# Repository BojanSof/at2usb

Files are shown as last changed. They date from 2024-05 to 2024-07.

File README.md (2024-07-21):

# AT (PS/2) keyboard to USB converter

PIC16F1459 solution for converting old AT (PS/2) keyboard to USB.

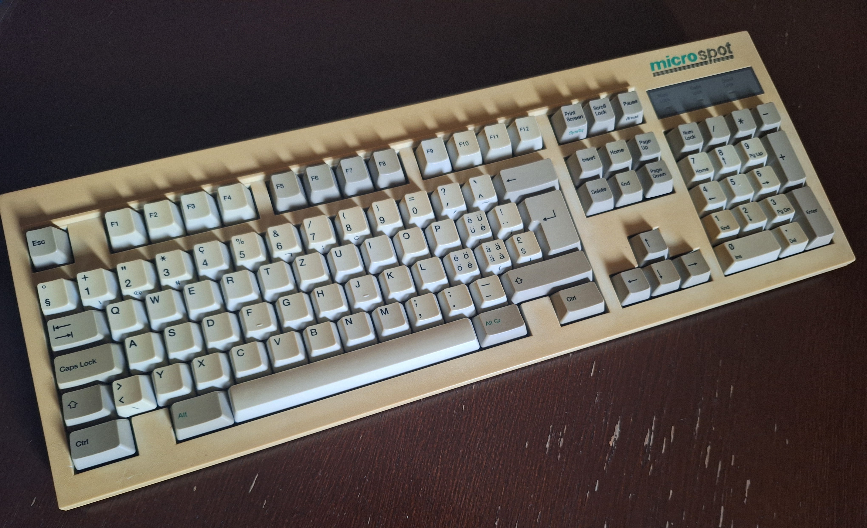
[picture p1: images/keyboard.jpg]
AT keyboard transformed to USB


## Hardware

Schematic and one layer PCB can be found under `hardware` directory.
The hardware design is created using KiCad 7.0.
The circuit is very simple and it can be created easily on prototyping board.

AT2USB schematic

## Firmware

The firmware is developed with MPLAB X IDE, found under `at2usbClassic.X` directory.
USB stack implementation and main HID app code is based on USB HID keyboard project from [Microchip Libraries for Applications (MLA)](https://www.microchip.com/en-us/tools-resources/develop/libraries/microchip-libraries-for-applications).

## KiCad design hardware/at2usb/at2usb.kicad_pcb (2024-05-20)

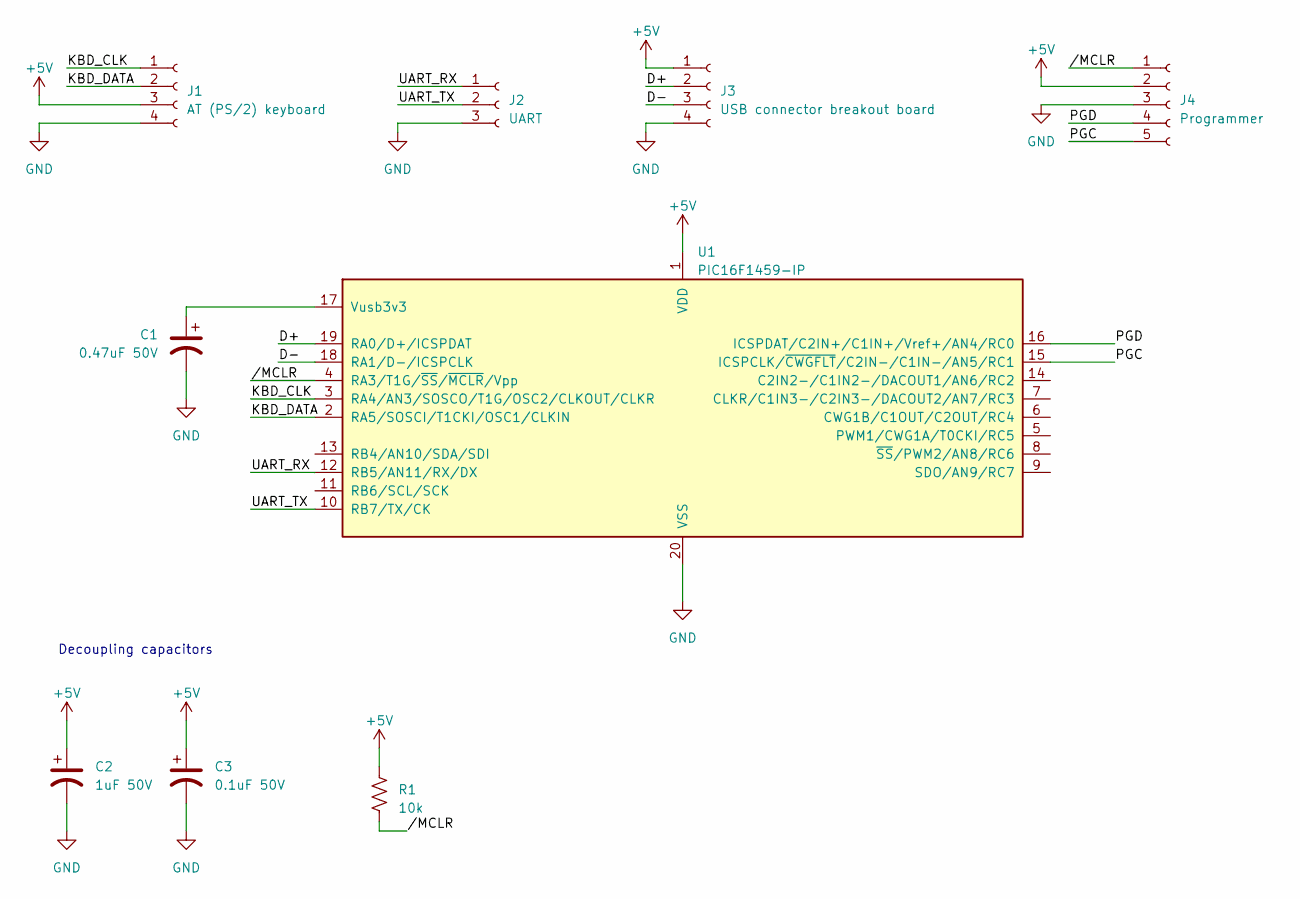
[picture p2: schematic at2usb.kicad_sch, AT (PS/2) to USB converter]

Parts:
C1: 0.47uF 50V; CP_Radial_D5.0mm_P2.00mm
C2: 1uF 50V; CP_Radial_D5.0mm_P2.00mm
C3: 0.1uF 50V; CP_Radial_D5.0mm_P2.00mm
J1: AT (PS/2) keyboard; PinHeader_1x04_P2.54mm_Vertical
J2: UART; PinHeader_1x03_P2.54mm_Vertical
J3: USB connector breakout board; PinHeader_1x04_P2.54mm_Vertical
J4: Programmer; PinHeader_1x05_P2.54mm_Vertical
R1: 10k; R_Axial_DIN0207_L6.3mm_D2.5mm_P2.54mm_Vertical
U1: PIC16F1459-IP; DIP-20_W7.62mm_Socket

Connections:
+5V: C2.1, C3.1, J1.3, J3.1, J4.2, R1.1, U1.1 (VDD)
/D+: J3.2, U1.19 (RA0/D+/ICSPDAT)
/D-: J3.3, U1.18 (RA1/D-/ICSPCLK)
/KBD_CLK: J1.1, U1.3 (RA4/AN3/SOSCO/T1G/OSC2/CLKOUT/CLKR)
/KBD_DATA: J1.2, U1.2 (RA5/SOSCI/T1CKI/OSC1/CLKIN)
/PGC: J4.5, U1.15 (ICSPCLK/~CWGFLT/C2IN-/C1IN-/AN5/RC1)
/PGD: J4.4, U1.16 (ICSPDAT/C2IN+/C1IN+/Vref+/AN4/RC0)
/UART_RX: J2.1, U1.12 (RB5/AN11/RX/DX)
/UART_TX: J2.2, U1.10 (RB7/TX/CK)
//MCLR: J4.1, R1.2, U1.4 (RA3/T1G/~SS/~MCLR/Vpp)
GND: C1.2, C2.2, C3.2, J1.4, J2.3, J3.4, J4.3, U1.20 (VSS)
unnamed: C1.1, U1.17 (Vusb3v3)

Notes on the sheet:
Decoupling capacitors

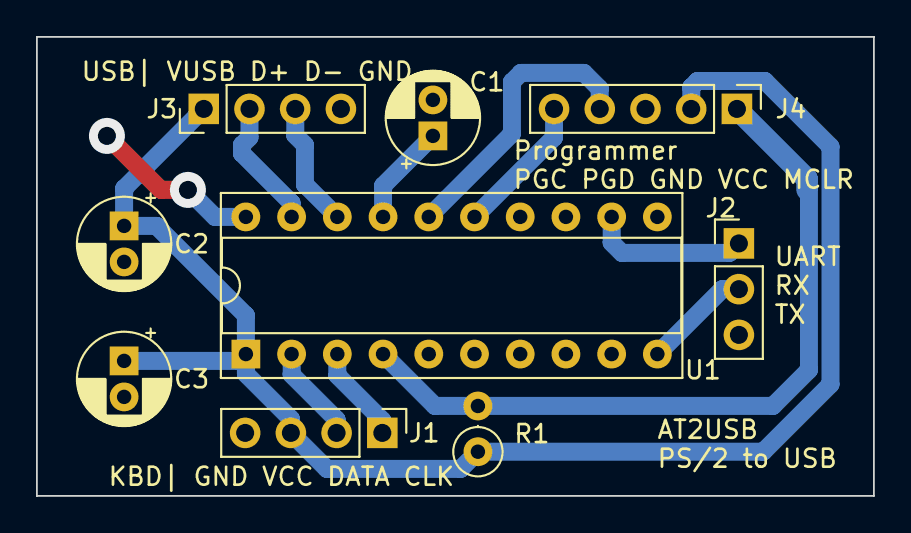
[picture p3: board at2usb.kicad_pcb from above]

Board: 2 copper layers, 46.5 x 25.5 mm, 9 parts (0 on the bottom side), 12 nets.

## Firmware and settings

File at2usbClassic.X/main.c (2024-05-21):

#include "mcc_generated_files/mcc.h"

#include "app_device_keyboard.h"
#include "systime.h"
#include "log.h"

/*
    Main application
 */

int main(void) {
    SYSTEM_Initialize();
    SysTime_Init();
    PS2Keyboard_Init();
    
    __delay_ms(1000);

    // If using interrupts in PIC18 High/Low Priority Mode you need to enable the Global High and Low Interrupts 
    // If using interrupts in PIC Mid-Range Compatibility Mode you need to enable the Global and Peripheral Interrupts 
    // Use the following macros to: 

    // Enable the Global Interrupts 
    INTERRUPT_GlobalInterruptEnable();

    // Enable the Peripheral Interrupts 
    INTERRUPT_PeripheralInterruptEnable();

    // Disable the Peripheral Interrupts 
    //INTERRUPT_PeripheralInterruptDisable();
    
    PS2ScanCode scanCode = {0};
    bool scanCodeValid = false;
    PS2ScanCode *hndlScanCode = NULL;
    char scanCodeStr[6] = {' ', ' ', ' ', ' ', '\r', '\n'};
    
    while (1) {
        scanCodeValid = PS2Keyboard_GetScanCode(&scanCode);
        if(scanCodeValid) {
            hndlScanCode = &scanCode;
        } else {
            hndlScanCode = NULL;
        }
        if(hndlScanCode != NULL) {
            scanCodeStr[0] = hndlScanCode->isExtend ? 'e' : ' ';
            scanCodeStr[1] = hndlScanCode->isBreak ? 'b' : ' ';
            Log_UtilityConvertByteToHex(hndlScanCode->value, &scanCodeStr[2], 2);
            Log_Message((const uint8_t*)scanCodeStr, sizeof(scanCodeStr));
        }
        APP_KeyboardTasks(hndlScanCode);
    }
}

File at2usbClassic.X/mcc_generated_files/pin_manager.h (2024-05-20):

/**
  @Generated Pin Manager Header File

  @Company:
    Microchip Technology Inc.

  @File Name:
    pin_manager.h

  @Summary:
    This is the Pin Manager file generated using PIC10 / PIC12 / PIC16 / PIC18 MCUs

  @Description
    This header file provides APIs for driver for .
    Generation Information :
        Product Revision  :  PIC10 / PIC12 / PIC16 / PIC18 MCUs - 1.81.8
        Device            :  PIC16F1459
        Driver Version    :  2.11
    The generated drivers are tested against the following:
        Compiler          :  XC8 2.36 and above
        MPLAB 	          :  MPLAB X 6.00	
*/

/*
    (c) 2018 Microchip Technology Inc. and its subsidiaries. 
    
    Subject to your compliance with these terms, you may use Microchip software and any 
    derivatives exclusively with Microchip products. It is your responsibility to comply with third party 
    license terms applicable to your use of third party software (including open source software) that 
    may accompany Microchip software.
    
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
    IN NO EVENT WILL MICROCHIP BE LIABLE FOR ANY INDIRECT, SPECIAL, PUNITIVE, 
    INCIDENTAL OR CONSEQUENTIAL LOSS, DAMAGE, COST OR EXPENSE OF ANY KIND 
    WHATSOEVER RELATED TO THE SOFTWARE, HOWEVER CAUSED, EVEN IF MICROCHIP 
    HAS BEEN ADVISED OF THE POSSIBILITY OR THE DAMAGES ARE FORESEEABLE. TO 
    THE FULLEST EXTENT ALLOWED BY LAW, MICROCHIP'S TOTAL LIABILITY ON ALL 
    CLAIMS IN ANY WAY RELATED TO THIS SOFTWARE WILL NOT EXCEED THE AMOUNT 
    OF FEES, IF ANY, THAT YOU HAVE PAID DIRECTLY TO MICROCHIP FOR THIS 
    SOFTWARE.
*/

#ifndef PIN_MANAGER_H
#define PIN_MANAGER_H

/**
  Section: Included Files
*/

#include <xc.h>

#define INPUT   1
#define OUTPUT  0

#define HIGH    1
#define LOW     0

#define ANALOG      1
#define DIGITAL     0

#define PULL_UP_ENABLED      1
#define PULL_UP_DISABLED     0

// get/set KBD_CLK aliases
#define KBD_CLK_TRIS                 TRISAbits.TRISA4
#define KBD_CLK_LAT                  LATAbits.LATA4
#define KBD_CLK_PORT                 PORTAbits.RA4
#define KBD_CLK_WPU                  WPUAbits.WPUA4
#define KBD_CLK_ANS                  ANSELAbits.ANSA4
#define KBD_CLK_SetHigh()            do { LATAbits.LATA4 = 1; } while(0)
#define KBD_CLK_SetLow()             do { LATAbits.LATA4 = 0; } while(0)
#define KBD_CLK_Toggle()             do { LATAbits.LATA4 = ~LATAbits.LATA4; } while(0)
#define KBD_CLK_GetValue()           PORTAbits.RA4
#define KBD_CLK_SetDigitalInput()    do { TRISAbits.TRISA4 = 1; } while(0)
#define KBD_CLK_SetDigitalOutput()   do { TRISAbits.TRISA4 = 0; } while(0)
#define KBD_CLK_SetPullup()          do { WPUAbits.WPUA4 = 1; } while(0)
#define KBD_CLK_ResetPullup()        do { WPUAbits.WPUA4 = 0; } while(0)
#define KBD_CLK_SetAnalogMode()      do { ANSELAbits.ANSA4 = 1; } while(0)
#define KBD_CLK_SetDigitalMode()     do { ANSELAbits.ANSA4 = 0; } while(0)

// get/set KBD_DATA aliases
#define KBD_DATA_TRIS                 TRISAbits.TRISA5
#define KBD_DATA_LAT                  LATAbits.LATA5
#define KBD_DATA_PORT                 PORTAbits.RA5
#define KBD_DATA_WPU                  WPUAbits.WPUA5
#define KBD_DATA_SetHigh()            do { LATAbits.LATA5 = 1; } while(0)
#define KBD_DATA_SetLow()             do { LATAbits.LATA5 = 0; } while(0)
#define KBD_DATA_Toggle()             do { LATAbits.LATA5 = ~LATAbits.LATA5; } while(0)
#define KBD_DATA_GetValue()           PORTAbits.RA5
#define KBD_DATA_SetDigitalInput()    do { TRISAbits.TRISA5 = 1; } while(0)
#define KBD_DATA_SetDigitalOutput()   do { TRISAbits.TRISA5 = 0; } while(0)
#define KBD_DATA_SetPullup()          do { WPUAbits.WPUA5 = 1; } while(0)
#define KBD_DATA_ResetPullup()        do { WPUAbits.WPUA5 = 0; } while(0)

// get/set RB7 procedures
#define RB7_SetHigh()            do { LATBbits.LATB7 = 1; } while(0)
#define RB7_SetLow()             do { LATBbits.LATB7 = 0; } while(0)
#define RB7_Toggle()             do { LATBbits.LATB7 = ~LATBbits.LATB7; } while(0)
#define RB7_GetValue()              PORTBbits.RB7
#define RB7_SetDigitalInput()    do { TRISBbits.TRISB7 = 1; } while(0)
#define RB7_SetDigitalOutput()   do { TRISBbits.TRISB7 = 0; } while(0)
#define RB7_SetPullup()             do { WPUBbits.WPUB7 = 1; } while(0)
#define RB7_ResetPullup()           do { WPUBbits.WPUB7 = 0; } while(0)

/**
   @Param
    none
   @Returns
    none
   @Description
    GPIO and peripheral I/O initialization
   @Example
    PIN_MANAGER_Initialize();
 */
void PIN_MANAGER_Initialize (void);

/**
 * @Param
    none
 * @Returns
    none
 * @Description
    Interrupt on Change Handling routine
 * @Example
    PIN_MANAGER_IOC();
 */
void PIN_MANAGER_IOC(void);


/**
 * @Param
    none
 * @Returns
    none
 * @Description
    Interrupt on Change Handler for the IOCAF4 pin functionality
 * @Example
    IOCAF4_ISR();
 */
void IOCAF4_ISR(void);

/**
  @Summary
    Interrupt Handler Setter for IOCAF4 pin interrupt-on-change functionality

  @Description
    Allows selecting an interrupt handler for IOCAF4 at application runtime
    
  @Preconditions
    Pin Manager intializer called

  @Returns
    None.

  @Param
    InterruptHandler function pointer.

  @Example
    PIN_MANAGER_Initialize();
    IOCAF4_SetInterruptHandler(MyInterruptHandler);

*/
void IOCAF4_SetInterruptHandler(void (* InterruptHandler)(void));

/**
  @Summary
    Dynamic Interrupt Handler for IOCAF4 pin

  @Description
    This is a dynamic interrupt handler to be used together with the IOCAF4_SetInterruptHandler() method.
    This handler is called every time the IOCAF4 ISR is executed and allows any function to be registered at runtime.
    
  @Preconditions
    Pin Manager intializer called

  @Returns
    None.

  @Param
    None.

  @Example
    PIN_MANAGER_Initialize();
    IOCAF4_SetInterruptHandler(IOCAF4_InterruptHandler);

*/
extern void (*IOCAF4_InterruptHandler)(void);

/**
  @Summary
    Default Interrupt Handler for IOCAF4 pin

  @Description
    This is a predefined interrupt handler to be used together with the IOCAF4_SetInterruptHandler() method.
    This handler is called every time the IOCAF4 ISR is executed. 
    
  @Preconditions
    Pin Manager intializer called

  @Returns
    None.

  @Param
    None.

  @Example
    PIN_MANAGER_Initialize();
    IOCAF4_SetInterruptHandler(IOCAF4_DefaultInterruptHandler);

*/
void IOCAF4_DefaultInterruptHandler(void);


/**
 * @Param
    none
 * @Returns
    none
 * @Description
    Interrupt on Change Handler for the IOCAF5 pin functionality
 * @Example
    IOCAF5_ISR();
 */
void IOCAF5_ISR(void);

/**
  @Summary
    Interrupt Handler Setter for IOCAF5 pin interrupt-on-change functionality

  @Description
    Allows selecting an interrupt handler for IOCAF5 at application runtime
    
  @Preconditions
    Pin Manager intializer called

  @Returns
    None.

  @Param
    InterruptHandler function pointer.

  @Example
    PIN_MANAGER_Initialize();
    IOCAF5_SetInterruptHandler(MyInterruptHandler);
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

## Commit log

2024-05-06 Fix prev time set for ps2 keyboard reset in case of error
2024-05-07 PS2 keyboard leds are only modified from HID output report, fixing compiler warnings
    [main.c]
2024-05-07 Add hardware design in KiCad, update Readme with more brief info
    [at2usb.kicad_pcb, at2usb.kicad_sch]
2024-05-19 Add gnd pin next to uart pins
    [at2usb.kicad_pcb, at2usb.kicad_sch]
2024-05-20 Add MCLR pull-up resistor in schematic, remove UART RX
    [at2usb.kicad_pcb, at2usb.kicad_sch]
